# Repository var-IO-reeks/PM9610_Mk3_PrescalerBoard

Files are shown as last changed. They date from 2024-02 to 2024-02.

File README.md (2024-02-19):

# PM9610_Mk3_PrescalerBoard

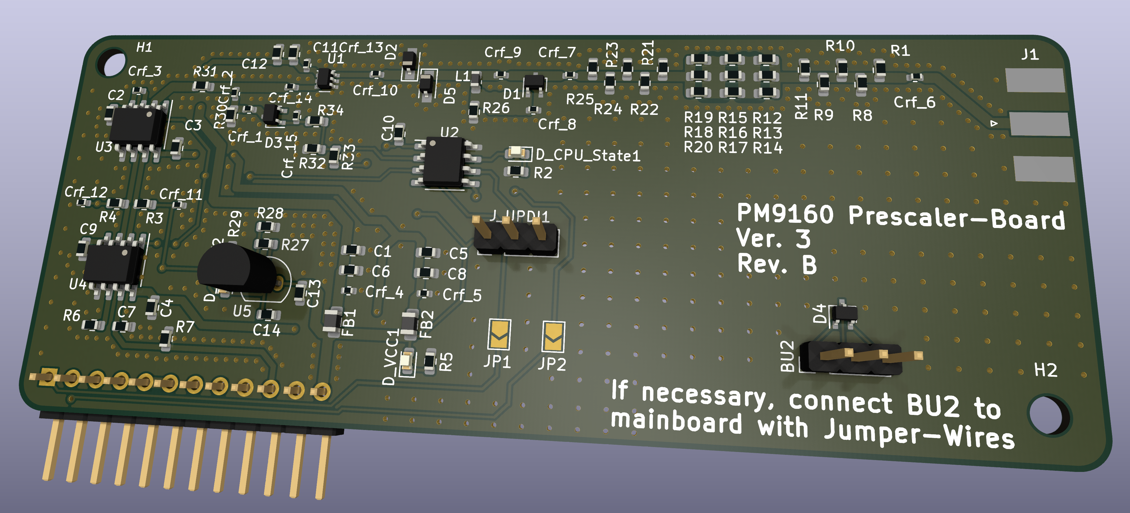
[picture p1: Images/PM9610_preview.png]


This is a fork of SaabFANs original "PM9160_Mk3_PrescalerBoard"-Project. I fixed some minor KiCad-Related Layout issues, cleaned up the schematic a little bit to improve readability and made the Board compatible with Aislers "Beautiful Boards Budget Simple" PCB manufacturing service.

This is a recreation of the PM9160 Prescaler-Board, used in the PM6654x Programmable Counters made by Philips back in the late 80s / early 90s. 
It divides incoming frequencies by 16. With this, a 2.4 Ghz Signal can be counted by the "Counter on a Chip"-Hardware inside the Counter, to which the signal is routed internally on the Mainboard. 

The board uses modern ICs to recreate the original function of the board, which makes it possible to put everything inside the 10x10cm Limit for a cheap 2 Layer Board from most board manufacturers. 
An AtTiny1616 Processor replaces the original analog circuit for the detection of an RF Signal Present and for the handling of Signals !B and TEST_GO. For better Accessibility during testing, the component side has been changed from the original Board. 
Software for the AtTiny1616 is written in C with the PlatformIO-IDE. 

Note: It might be necessary to use longer Pin Headers for the connectors. Make sure, the pins are not too long though, as they can touch the case and short out the 5V and -8.5V Rails!

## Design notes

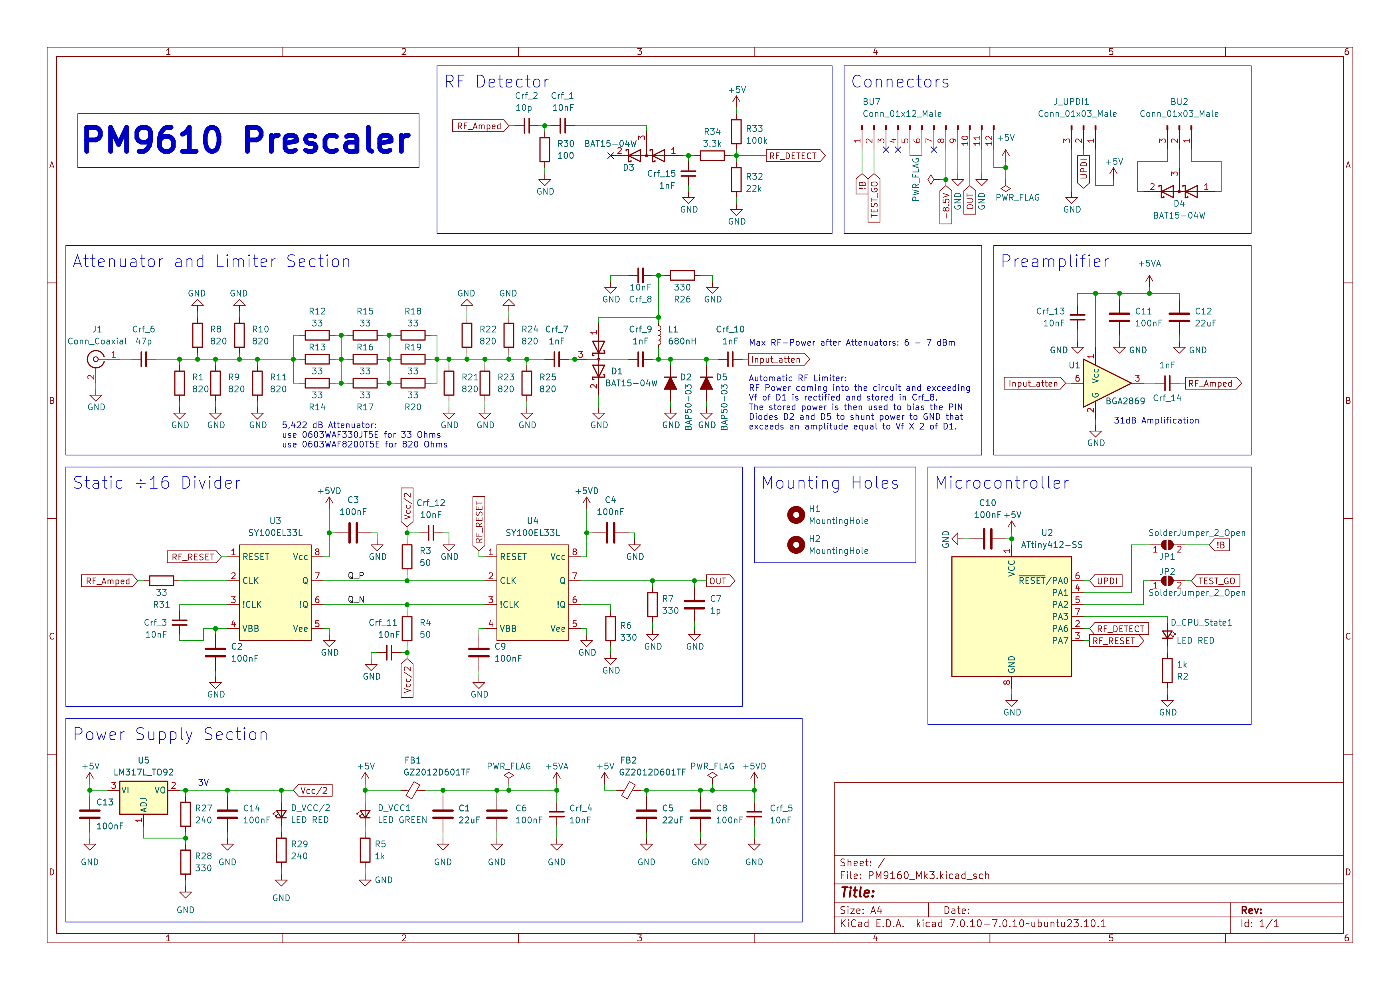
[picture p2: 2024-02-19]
Images/PM9160_Mk3_schematic.png

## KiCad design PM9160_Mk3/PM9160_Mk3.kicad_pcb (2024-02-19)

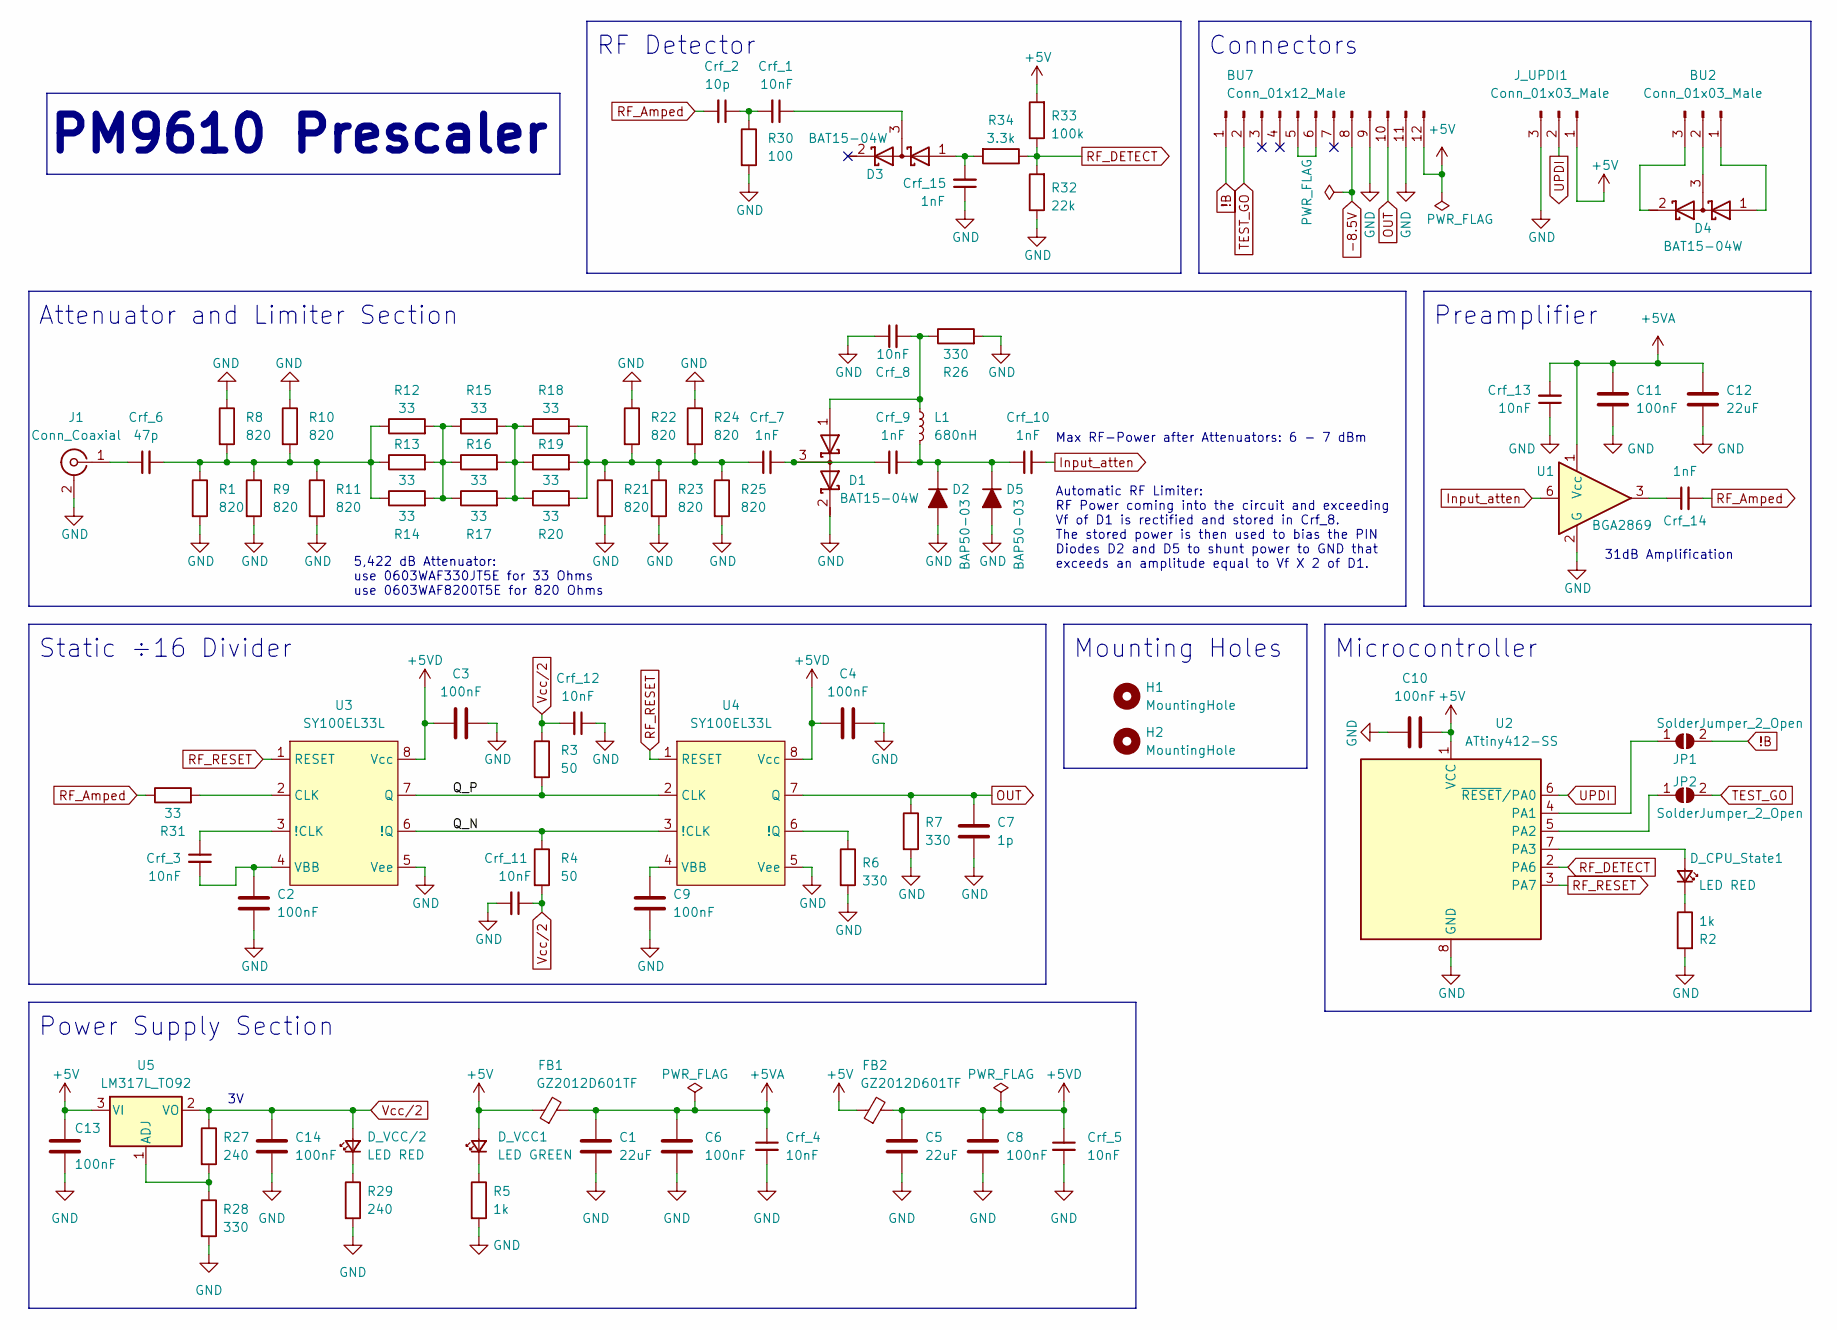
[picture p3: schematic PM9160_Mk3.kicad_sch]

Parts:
BU2: Conn_01x03_Male; PinHeader_1x03_P2.54mm_Vertical
BU7: Conn_01x12_Male; PinHeader_1x12_P2.54mm_Horizontal
C1, C5, C12: 22uF; C_0603_1608Metric
C2, C3, C4, C6, C8, C9, C10, C11, C13, C14: 100nF; C_0603_1608Metric
C7: 1p; C_0603_1608Metric
Crf_1, Crf_3, Crf_4, Crf_5, Crf_8, Crf_11, Crf_12, Crf_13: 10nF; C_0402_1005Metric
Crf_2: 10p; C_0402_1005Metric
Crf_6: 47p; C_0402_1005Metric
Crf_7, Crf_9, Crf_10, Crf_14, Crf_15: 1nF; C_0402_1005Metric
D1, D3, D4: BAT15-04W; SOT-323_SC-70
D2, D5: BAP50-03; D_SOD-323_HandSoldering
D_CPU_State1: LED RED; LED_0603_1608Metric
D_VCC1: LED GREEN; LED_0603_1608Metric
D_VCC/2: LED RED; LED_0603_1608Metric
FB1, FB2: GZ2012D601TF; L_0805_2012Metric
H1, H2: MountingHole; MountingHole_3.2mm_M3_DIN965
J1: Conn_Coaxial; SMA_Molex_73251-1153_EdgeMount_Horizontal
JP1, JP2: SolderJumper_2_Open; SolderJumper-2_P1.3mm_Open_TrianglePad1.0x1.5mm
J_UPDI1: Conn_01x03_Male; PinHeader_1x03_P2.54mm_Vertical
L1: 680nH; L_0603_1608Metric
R1, R8, R9, R10, R11, R21, R22, R23, R24, R25: 820; R_0603_1608Metric
R2, R5: 1k; R_0603_1608Metric
R3, R4: 50; R_0603_1608Metric
R6, R7, R26, R28: 330; R_0603_1608Metric
R12, R13, R14, R15, R16, R17, R18, R19, R20, R31: 33; R_0603_1608Metric
R27, R29: 240; R_0603_1608Metric
R30: 100; R_0603_1608Metric
R32: 22k; R_0603_1608Metric
R33: 100k; R_0603_1608Metric
R34: 3.3k; R_0603_1608Metric
U1: BGA2869; SOT-363_SC-70-6
U2: ATtiny412-SS; SOIC-8_3.9x4.9mm_P1.27mm
U3, U4: SY100EL33L; SOIC-8_3.9x4.9mm_P1.27mm
U5: LM317L_TO92; TO-92_Inline

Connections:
!B: BU7.1, JP1.2 (B)
+5V: BU7.12, C10.2, C13.1, D_VCC1.2 (A), FB1.1, FB2.1, J_UPDI1.1, R33.2, U2.1 (VCC), U5.3 (VI)
+5VA: C1.1, C6.1, C11.2, C12.1, Crf_4.1, Crf_13.2, FB1.2, U1.1 (Vcc)
+5VD: C3.1, C4.1, C5.1, C8.1, Crf_5.1, FB2.2, U3.8 (Vcc), U4.8 (Vcc)
-8.5V: BU7.8
/Q_N: R4.1, U3.6 (!Q), U4.3 (!CLK)
/Q_P: R3.2, U3.7 (Q), U4.2 (CLK)
GND: BU7.9, BU7.11, C1.2, C2.2, C3.2, C4.2, C5.2, C6.2, C7.2, C8.2, C9.2, C10.1, C11.1, C12.2, C13.2, C14.2, Crf_4.2, Crf_5.2, Crf_8.1, Crf_11.2, Crf_12.1, Crf_13.1, Crf_15.1, D1.2 (K), D2.2 (A), D5.2 (A), J1.2 (Ext), J_UPDI1.3, R1.2, R2.2, R5.2, R6.2, R7.2, R8.1, R9.2, R10.1, R11.2, R21.2, R22.1, R23.2, R24.1, R25.2, R26.2, R28.2, R29.2, R30.2, R32.1, U1.2 (G), U1.4 (G), U1.5 (G), U2.8 (GND), U3.5 (Vee), U4.5 (Vee)
Input_atten: Crf_10.2, U1.6
unnamed: BU2.1, D4.1 (A)
unnamed: BU2.2, D4.3 (common)
unnamed: BU2.3, D4.2 (K)
unnamed: BU7.5, BU7.6
unnamed: Crf_1.2, Crf_2.1, R30.1
unnamed: Crf_6.2, R1.1, R8.2, R9.1, R10.2, R11.1, R12.1, R13.1, R14.1
unnamed: Crf_7.1, R18.2, R19.2, R20.2, R21.1, R22.2, R23.1, R24.2, R25.1
unnamed: Crf_14.1, U1.3
unnamed: Crf_8.2, D1.1 (A), L1.1, R26.1
unnamed: Crf_7.2, Crf_9.1, D1.3 (common)
unnamed: Crf_9.2, Crf_10.1, D2.1 (K), D5.1 (K), L1.2
unnamed: Crf_15.2, D3.1 (A), R34.2
unnamed: Crf_1.1, D3.3 (common)
unnamed: D_CPU_State1.2 (A), U2.7 (PA3)
unnamed: D_CPU_State1.1 (K), R2.1
unnamed: D_VCC1.1 (K), R5.1
unnamed: D_VCC/2.1 (K), R29.1
unnamed: Crf_6.1, J1.1 (In)
unnamed: JP1.1 (A), U2.4 (PA1)
unnamed: JP2.1 (A), U2.5 (PA2)
unnamed: R12.2, R13.2, R14.2, R15.1, R16.1, R17.1
unnamed: R15.2, R16.2, R17.2, R18.1, R19.1, R20.1
unnamed: Crf_3.1, U3.3 (!CLK)
unnamed: R31.2, U3.2 (CLK)
unnamed: C2.1, Crf_3.2, U3.4 (VBB)
unnamed: R6.1, U4.6 (!Q)
unnamed: C9.1, U4.4 (VBB)
unnamed: R27.2, R28.1, U5.1 (ADJ)
OUT: BU7.10, C7.1, R7.1, U4.7 (Q)
RF_Amped: Crf_2.2, Crf_14.2, R31.1
RF_DETECT: R32.2, R33.1, R34.1, U2.2 (PA6)
RF_RESET: U2.3 (PA7), U3.1 (RESET), U4.1 (RESET)
TEST_GO: BU7.2, JP2.2 (B)
UPDI: J_UPDI1.2, U2.6 (~RESET/PA0)
Vcc/2: C14.1, Crf_11.1, Crf_12.2, D_VCC/2.2 (A), R3.1, R4.2, R27.1, U5.2 (VO)

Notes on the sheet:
Power Supply Section
PM9610 Prescaler
Automatic RF Limiter: RF Power coming into the circuit and exceeding Vf of D1 is rectified and stored in Crf_8. The stored power is then used to bias the PIN Diodes D2 and D5 to shunt power to GND that exceeds an amplitude equal to Vf X 2 of D1.
Max RF-Power after Attenuators: 6 - 7 dBm
Microcontroller
RF Detector
Static ÷16 Divider
5,422 dB Attenuator: use 0603WAF330JT5E for 33 Ohms use 0603WAF8200T5E for 820 Ohms
Preamplifier
Connectors
Mounting Holes
Attenuator and Limiter Section
31dB Amplification

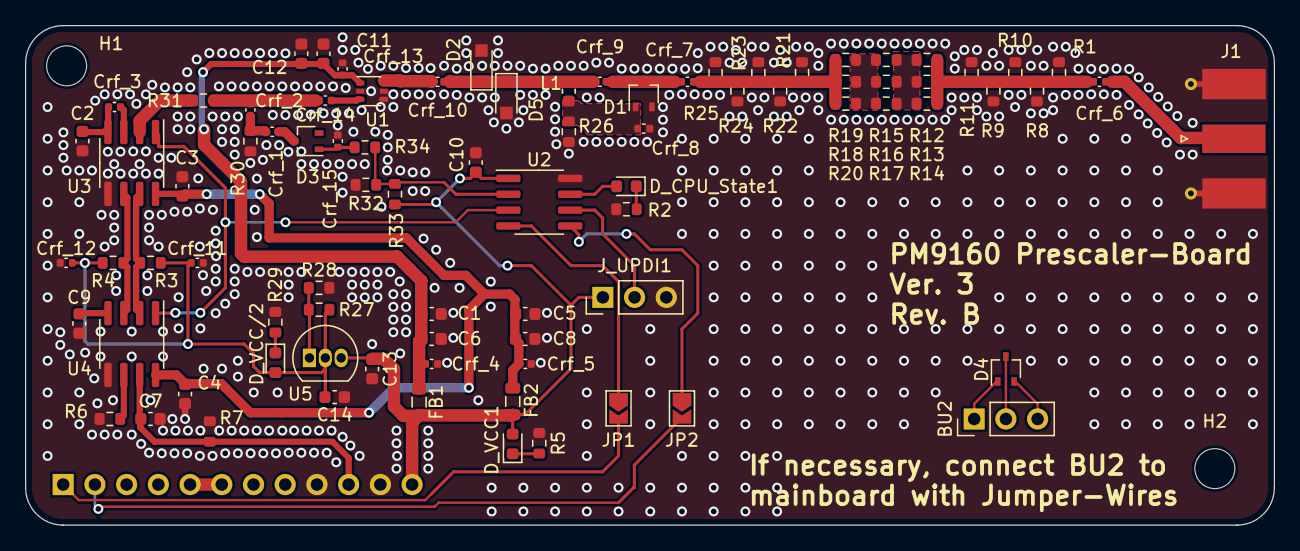
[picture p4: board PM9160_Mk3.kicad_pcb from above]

Board: 2 copper layers, 100.0 x 40.0 mm, 87 parts (1 on the bottom side), 43 nets.

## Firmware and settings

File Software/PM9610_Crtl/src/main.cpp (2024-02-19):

#include <Arduino.h>

// Pin-Definitions
#define RF_DETECT PIN_PA1
#define RF_RESET PIN_PA2
#define B PIN_PA3
#define CPU_STATE PIN_PA6
#define TEST_GO PIN_PA7

#define RF_THRESHOLD 500  // Threshold Voltage at which RF-Signal is strong enough to be reliably detected by the Divider-Chips
#define ADC_VREF 2500.0  // Internal Reference Voltage of the ADC in mV

float voltRead(uint8_t pin);

void setup() {
  // put your setup code here, to run once:
  pinMode(RF_DETECT, INPUT);
  pinMode(RF_RESET, OUTPUT);
  pinMode(B, INPUT_PULLUP);
  pinMode(CPU_STATE, OUTPUT);
  pinMode(TEST_GO, INPUT_PULLUP);
  digitalWrite(RF_RESET, HIGH);
  digitalWrite(CPU_STATE, LOW);
  if(ADC_VREF < 5000){
    analogReference(INTERNAL2V5);
  } else {
    analogReference(INTERNAL4V3);
  }
}

void loop() {
  // put your main code here, to run repeatedly:
  if(voltRead(RF_DETECT) > RF_THRESHOLD){
    digitalWrite(CPU_STATE, HIGH);
  } else {
    digitalWrite(CPU_STATE, LOW);
  }
}

/*
  @brief Read voltage from a pin by using the analogRead-Function to get raw ADC Value and then convert it to a voltage value.
  @param pin: Pin to read voltage from
  @return Voltage in mV
*/
float voltRead(uint8_t pin) {
  return (ADC0_RES * ADC_VREF) / 1023.0;
}

// TODO: Setup Timers for timer-based check of the RF-Detect-Pin
// TODO: ISR for the Timer Interrupt based approach
// TODO: Implement the RF-Reset-Functionality

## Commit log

2023-08-04 Added KiCAD Files and the ATSTART-File for configuring the Mikrocontroller.
    [PM9160_Mk3.kicad_pcb, PM9160_Mk3.kicad_sch]
2024-02-12 Minor Changes to PCB layout, cleaned up schematic, fixed some DRC/ERC errors and warnings, made board compatible with Aislers "simple" PCB Service
    [PM9160_Mk3.kicad_pcb, PM9160_Mk3.kicad_sch]
2024-02-18 changed microcontroller to SOIC-8 Attiny412 for easier handsoldering.
    [PM9160_Mk3.kicad_pcb, PM9160_Mk3.kicad_sch]
2024-02-19 Changed resistor-footprints of the capacitors to proper capacitor footprints.
    [PM9160_Mk3.kicad_pcb, PM9160_Mk3.kicad_sch]
